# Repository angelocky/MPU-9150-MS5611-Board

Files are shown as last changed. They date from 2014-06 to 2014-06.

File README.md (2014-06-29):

MPU-9150-MS5611-Board
=====================
For the MPU-9150 and MS5611 Breakout Board. 

Arduino Library for the MPU-9150: [https://github.com/sparkfun/MPU-9150_Breakout/tree/master/firmware](https://github.com/sparkfun/MPU-9150_Breakout/tree/master/firmware)

Arduino Library for the MS5611 from Varesano.net: [http://www.varesano.net/files/FreeIMU-20121122_1126.zip](http://www.varesano.net/files/FreeIMU-20121122_1126.zip)

"MPU_9150_5611_example.ino" is an example sketch, to show functionality of the board. Individual example sketches can be found in their respective libraries.

Credit is due to the respective creators of the code.

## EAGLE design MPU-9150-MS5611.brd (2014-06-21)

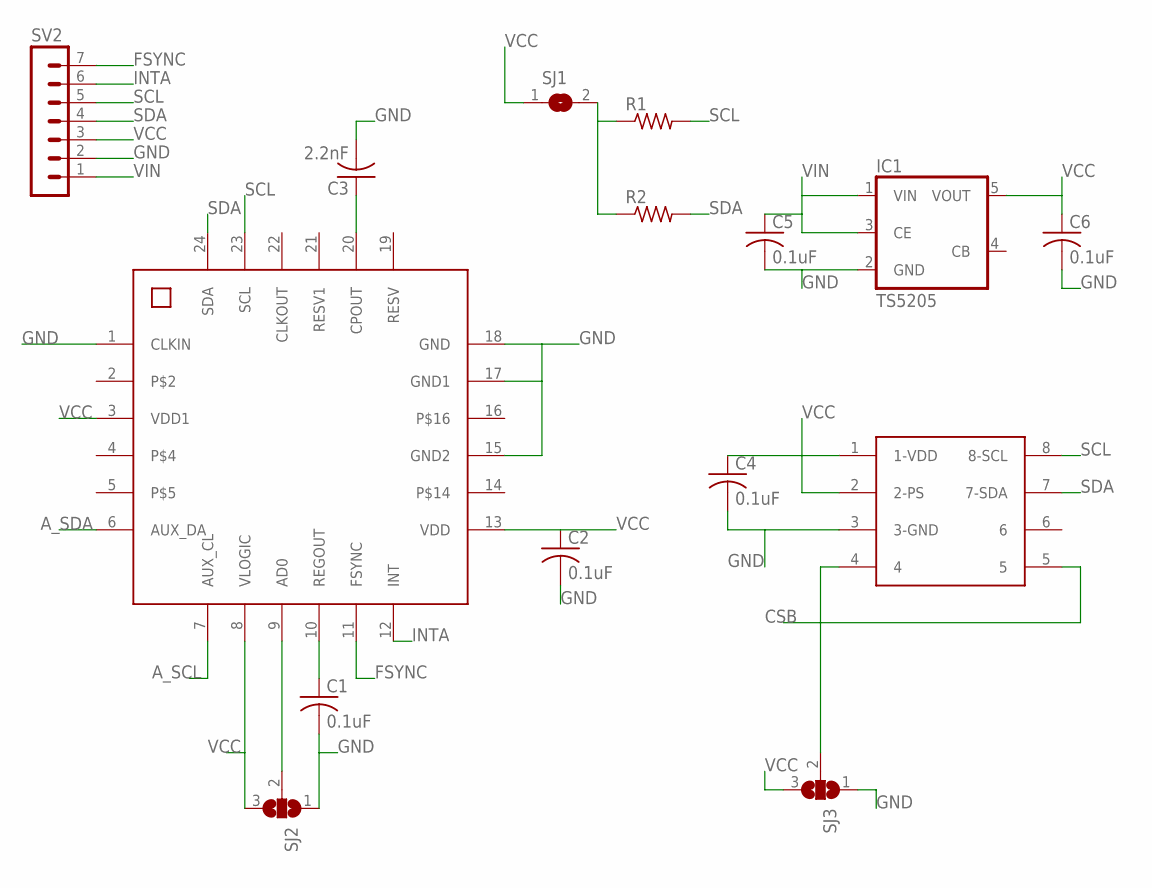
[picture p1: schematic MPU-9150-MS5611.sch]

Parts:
C1, C2, C4, C5, C6: 0.1uF; C0603
C3: 2.2nF; C0603
IC1: TS5205; SOT25
MPU-9150: MPU-9150MPU-9150; MPU-6050_QFN-24
MS5611: MS5611; MS5611-PACKAGE
R1, R2: R-US_R0603; R0603
SJ1: SJ
SJ2, SJ3: SJ2W; SJ_2
SV2: MA07-1

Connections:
9: MPU-9150.9 (AD0), SJ2.2
A_SCL: MPU-9150.7 (AUX_CL)
A_SDA: MPU-9150.6 (AUX_DA)
CSB: MS5611.4, MS5611.5, SJ3.2
FSYNC: MPU-9150.11 (FSYNC), SV2.7
GND: C1.2, C2.2, C3.2, C4.2, C5.2, C6.2, IC1.2 (GND), MPU-9150.1 (CLKIN), MPU-9150.15 (GND2), MPU-9150.17 (GND1), MPU-9150.18 (GND), MS5611.3 (3-GND), SJ2.1, SJ3.1, SV2.2
INTA: MPU-9150.12 (INT), SV2.6
unnamed: C1.1, MPU-9150.10 (REGOUT)
unnamed: C3.1, MPU-9150.20 (CPOUT)
PU: R1.1, R2.1, SJ1.2
SCL: MPU-9150.23 (SCL), MS5611.8 (8-SCL), R1.2, SV2.5
SDA: MPU-9150.24 (SDA), MS5611.7 (7-SDA), R2.2, SV2.4
VCC: C2.1, C4.1, C6.1, IC1.5 (VOUT), MPU-9150.3 (VDD1), MPU-9150.8 (VLOGIC), MPU-9150.13 (VDD), MS5611.1 (1-VDD), MS5611.2 (2-PS), SJ1.1, SJ2.3, SJ3.3, SV2.3
VIN: C5.1, IC1.1 (VIN), IC1.3 (CE), SV2.1

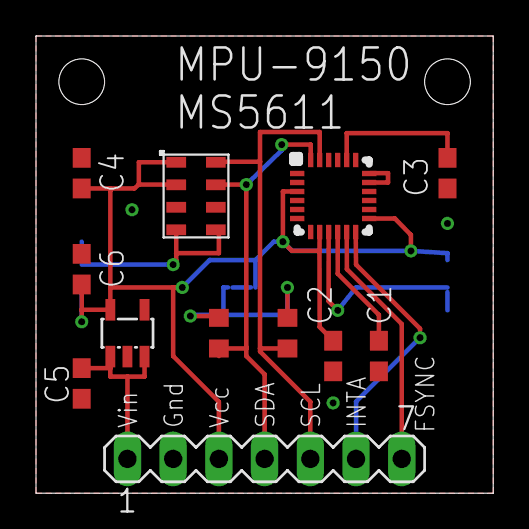
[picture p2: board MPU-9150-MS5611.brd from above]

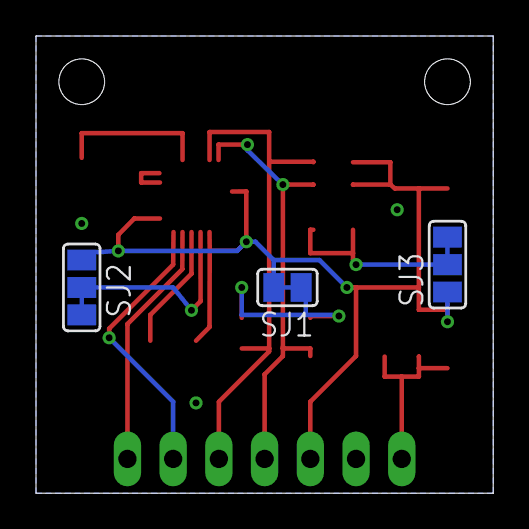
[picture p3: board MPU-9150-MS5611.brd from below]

Board: 2 copper layers, 25.4 x 25.4 mm, 15 parts (3 on the bottom side), 12 nets.

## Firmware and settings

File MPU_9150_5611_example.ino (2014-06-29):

//This Sketch is a combination of the MS5611 and MPU-9150 Example sketches, intended for use with the MS5611 - MPU-9150 Board.

/*
MS561101BA_altitude.pde - Computes altitude from sea level using pressure readings from the sensor.
The algorithm uses the Hypsometric formula as explained in http://keisan.casio.com/has10/SpecExec.cgi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

Copyright (C) 2011 Fabio Varesano <fvaresano@yahoo.it>

Development of this code has been supported by the Department of Computer Science,
Universita' degli Studi di Torino, Italy within the Piemonte Project
http://www.piemonte.di.unito.it/


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
*/

// I2C device class (I2Cdev) demonstration Arduino sketch for MPU9150
// 1/4/2013 original by Jeff Rowberg <jeff@rowberg.net> at https://github.com/jrowberg/i2cdevlib
//          modified by Aaron Weiss <aaron@sparkfun.com>
//
// Changelog:
//     2011-10-07 - initial release
//     2013-1-4 - added raw magnetometer output

/* ============================================
I2Cdev device library code is placed under the MIT license

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
THE SOFTWARE IS PROVIDED "AS IS", WITHOUT WARRANTY OF ANY KIND, EXPRESS OR
IMPLIED, INCLUDING BUT NOT LIMITED TO THE WARRANTIES OF MERCHANTABILITY,
FITNESS FOR A PARTICULAR PURPOSE AND NONINFRINGEMENT. IN NO EVENT SHALL THE
AUTHORS OR COPYRIGHT HOLDERS BE LIABLE FOR ANY CLAIM, DAMAGES OR OTHER
LIABILITY, WHETHER IN AN ACTION OF CONTRACT, TORT OR OTHERWISE, ARISING FROM,
OUT OF OR IN CONNECTION WITH THE SOFTWARE OR THE USE OR OTHER DEALINGS IN
THE SOFTWARE.
===============================================
*/

#include <Wire.h>
#include <MS561101BA.h>
#include "Wire.h"
#include "I2Cdev.h"
#include "MPU6050.h"

#define MOVAVG_SIZE 32

MS561101BA baro = MS561101BA();

float movavg_buff[MOVAVG_SIZE];
int movavg_i=0;

const float sea_press = 1013.25;
float press, temperature;

MPU6050 accelgyro;

int16_t ax, ay, az;
int16_t gx, gy, gz;
int16_t mx, my, mz;

void setup() {
  Wire.begin();
  Serial.begin(57600);
  delay(500);
  
  Serial.println("Initializing I2C devices...");
  accelgyro.initialize();
  Serial.println("Testing device connections...");
  Serial.println(accelgyro.testConnection() ? "MPU6050 connection successful" : "MPU6050 connection failed");

  baro.init(MS561101BA_ADDR_CSB_LOW); 
  delay(100);
  
  for(int i=0; i<MOVAVG_SIZE; i++) {
    movavg_buff[i] = baro.getPressure(MS561101BA_OSR_4096);
  }
}

void loop() {
  accelgyro.getMotion9(&ax, &ay, &az, &gx, &gy, &gz, &mx, &my, &mz);

  Serial.print(" temp: ");
  temperature = baro.getTemperature(MS561101BA_OSR_4096);
  Serial.print(temperature);
  Serial.print(" degC pres: ");
  
  press = baro.getPressure(MS561101BA_OSR_4096);
  //The following two lines "average" the values of the MS5611. If used, they do cause a lag.
  //pushAvg(press);
  //press = getAvg(movavg_buff, MOVAVG_SIZE);
  Serial.print(press);
  Serial.print(" mbar alt: ");
  Serial.print(getAltitude(press, temperature));
  Serial.print(" m\t");
  Serial.print("a/g/m:\t");
  Serial.print(ax); Serial.print("\t");
  Serial.print(ay); Serial.print("\t");
  Serial.print(az); Serial.print("\t");
  Serial.print(gx); Serial.print("\t");
  Serial.print(gy); Serial.print("\t");
  Serial.print(gz); Serial.print("\t");
  Serial.print(mx); Serial.print("\t");
  Serial.print(my); Serial.print("\t");
  Serial.println(mz);
  delay(50);
}

float getAltitude(float press, float temp) {
  //return (1.0f - pow(press/101325.0f, 0.190295f)) * 4433000.0f;
  return ((pow((sea_press / press), 1/5.257) - 1.0) * (temp + 273.15)) / 0.0065;
}

void pushAvg(float val) {
  movavg_buff[movavg_i] = val;
  movavg_i = (movavg_i + 1) % MOVAVG_SIZE;
}

float getAvg(float * buff, int size) {
  float sum = 0.0;
  for(int i=0; i<size; i++) {
    sum += buff[i];
  }
  return sum / size;
}

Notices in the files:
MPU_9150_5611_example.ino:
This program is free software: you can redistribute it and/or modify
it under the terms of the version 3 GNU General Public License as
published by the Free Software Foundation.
